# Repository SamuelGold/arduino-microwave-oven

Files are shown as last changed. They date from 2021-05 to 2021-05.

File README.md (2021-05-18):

# A second life for an old microwave oven

<p align="center">
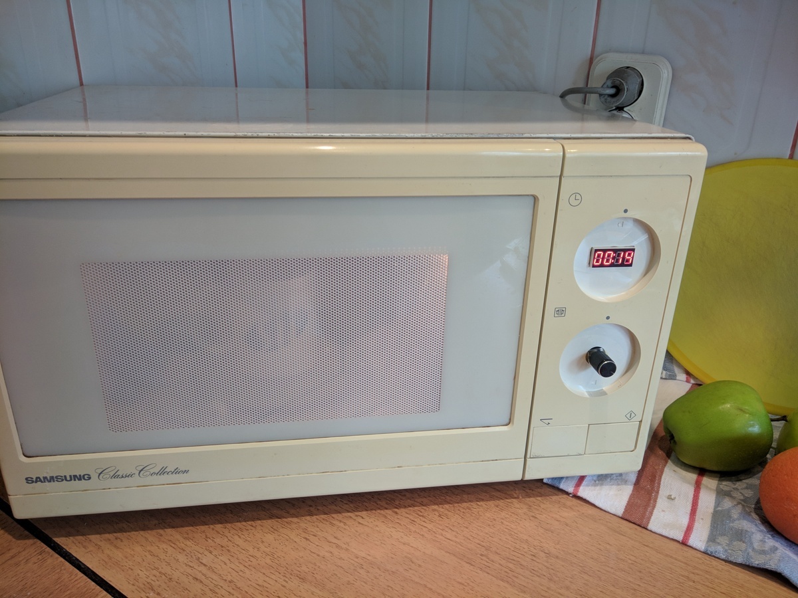
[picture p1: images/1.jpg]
  
</p>

I have a 28 years old oven, Samsung M7136. It so old, than this photo is probably only one of this model on the Internet :)

<p align="center">
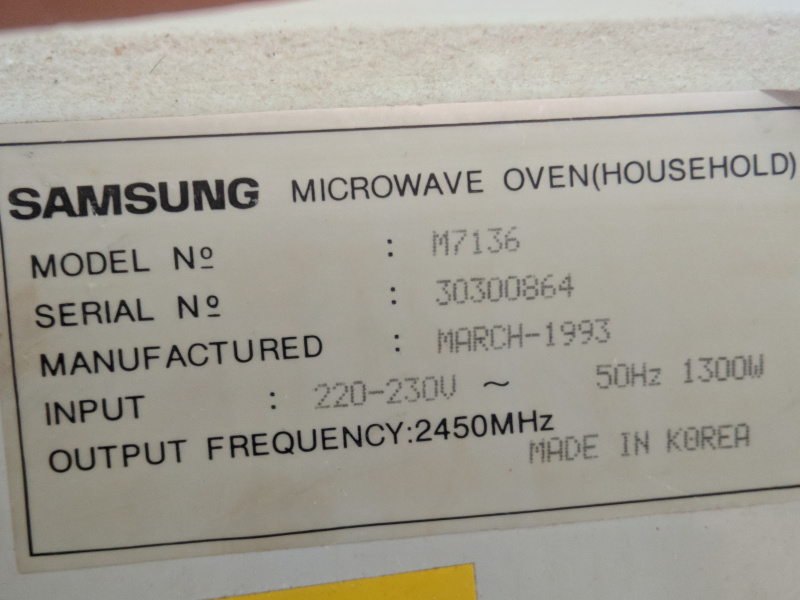
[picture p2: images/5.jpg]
  
</p>

The microwave had been working great, but but one day it stopped. One gear became broken:

<p align="center">
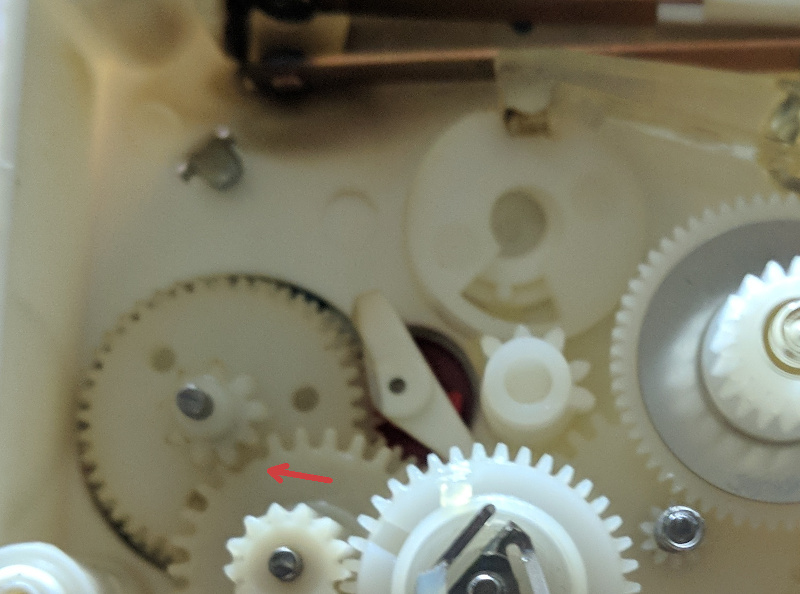
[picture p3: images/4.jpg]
broken mechanism
  
</p>

It was a pity to loose such a great oven an I did not want to multiply waste as well, so I decided to replace its mecanical timer with an electronic one.
If you decide to repeat this experience, please do not remove any switches around the door or termal protections from your oven :)

## Components:

1. Arduino NANO;
2. 2 pcs. 5V 10A x 250V relays, but it is recommended to use 30A relay for the microwave switch instead of 10A one;
3. KY-040 encoder module;
4. TM1637 display module;
5. 5V active buzzer;
6. 5V power supply.

## Connection schematic:

<p align="center">
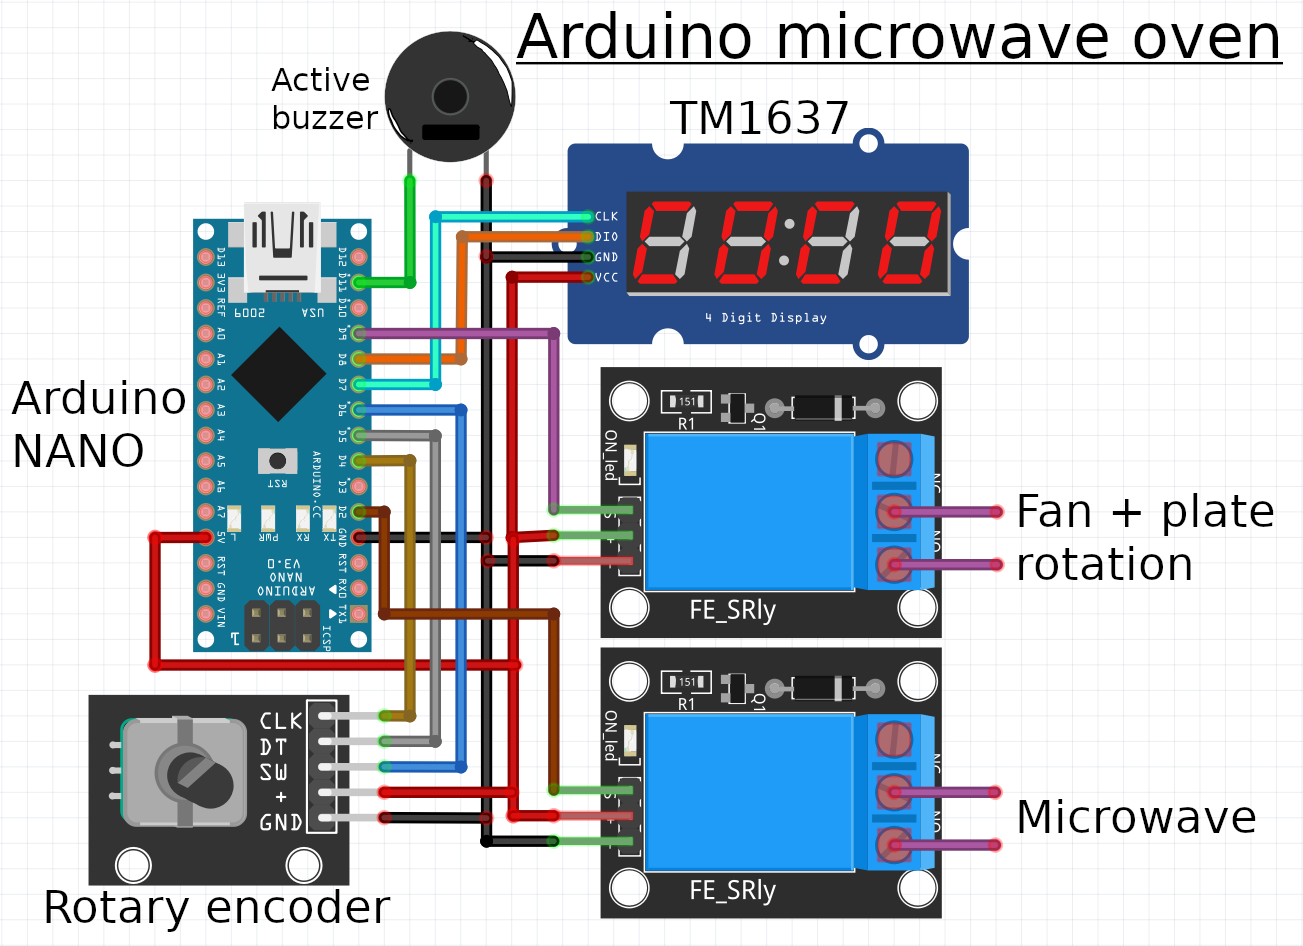
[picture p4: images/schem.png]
  
</p>

## Functionality:
Turn the encoder knob clockwise to start timer and heating process, turn the knob counterclockwise to decrease time and turn it off. Short press on the knob in the turned off state to show the current power level. Long press on the knob in turned off state to change the power level.

Arduino project code is included in this repo.
<p align="center">
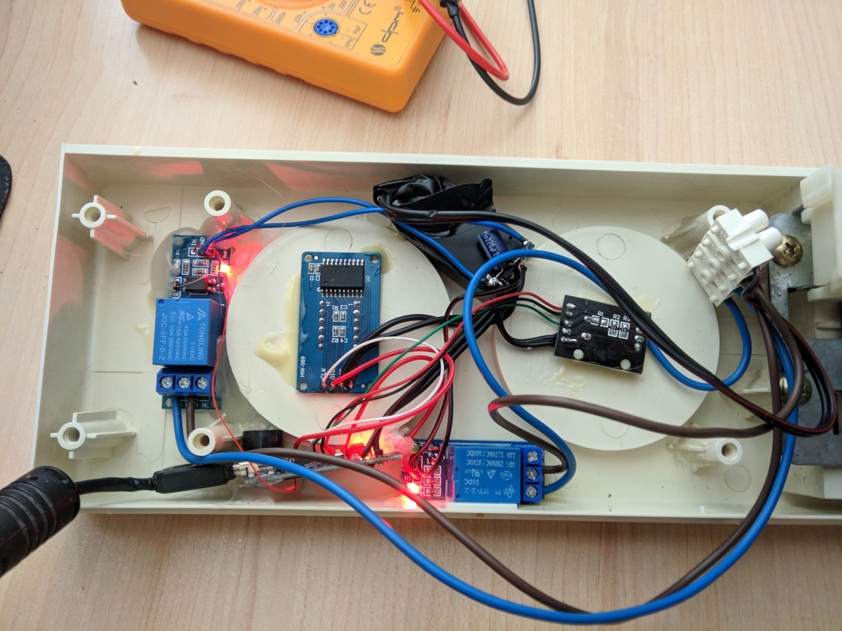
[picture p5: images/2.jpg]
  
</p>

<p align="center">
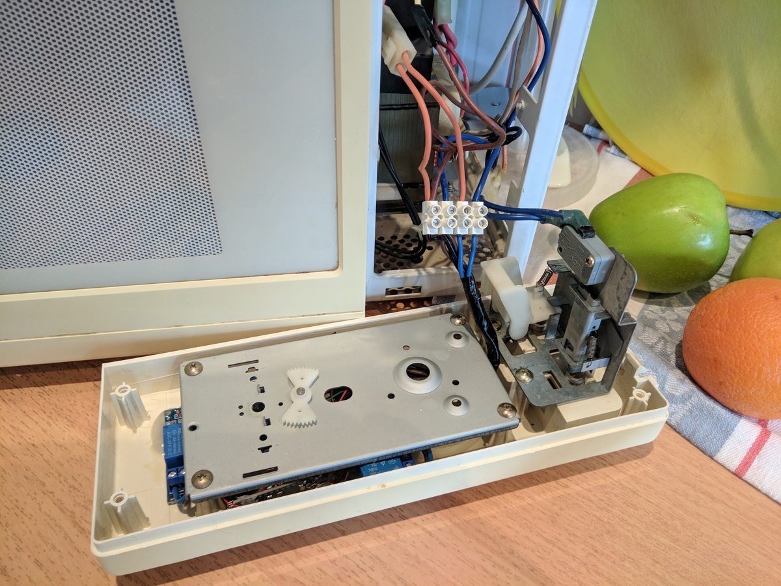
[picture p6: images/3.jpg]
  
</p>

 Remember about safety and have a fun :)

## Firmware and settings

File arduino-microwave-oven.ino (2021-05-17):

#include <TM1637.h>   //Grove segment display library
#include <Encoder.h>  //Paul Stoffregen's encoder library
#include <TimerOne.h>
#include <EEPROM.h>

#define BUZZER_pin         11 /* Active buzzer pin. */
#define DISPLAY_DATA_pin    8 /* TM1637 display data pin. */
#define DISPLAY_CLK_pin     7 /* TM1637 display clock pin. */
#define ENCODER_SW_pin      6 /* Rotary encoder button pin. */
#define ENCODER_DT_pin      5 /* Rotary encoder DT pin. */
#define ENCODER_CLK_pin     4 /* Rotary encoder CLK pin. */
#define MICROWAVE_RELAY_pin 2 /* Relay pin, that turns microwave power on. */
#define MOTOR_FAN_RELAY_pin 9 /* Relay pin, that turns cooler fan and food rotation motor on. */

#define POWER_max        5 /* Power levels number. */
#define POWER_CNTR_mul   4 /* Seconds per one power level. POWER_max * POWER_CNTR_mul = total power cycle time. */
#define SECONDS_max      1200 /* Maximal working time. */
#define SECONDS_CNTR_mul 3 /* Seconds per encoder rotation tik sensivity. */
#define SECONDS_CNTR_max SECONDS_max * SECONDS_CNTR_mul
#define TIME_CNTR_SPEEDUP 30 /* Timer value, after that we should increase the time faster by encoder rotation. */
#define FAN_AFTER_OFF_TIME 5 /* Time to keep fan on after microwaving finished. */

TM1637 disp(DISPLAY_CLK_pin,DISPLAY_DATA_pin);
Encoder knob(ENCODER_DT_pin, ENCODER_CLK_pin);

static int time_counter = 0;
static uint32_t power = 1;
static uint32_t power_counter = 0;
static uint32_t relay_state = 0;
static uint32_t motor_fan_state = 0;
static uint32_t motor_fan_counter = 0;
static long oldPosition = 0;
unsigned long oldMills;
static int finish = 0;
static int updateDisplay = 0;
static int updatePower = 0;
static int displayPower = 0;
static int silent_off = 0;
static int reduse_noise = 0;

static int melody_durations[] = {
6, 8, 8, 8, 16, 10, 10
};

static int pause_durations[] = {
16, 4, 4, 8, 18, 6, 6
};

/* Melody play at the end, used an active buzzer that sounds on power on by itself. */
void beep(){
  
  for (int i = 0; i < sizeof(melody_durations)/sizeof(melody_durations[0]); i++)
  {
    digitalWrite(BUZZER_pin, HIGH);
    delay((melody_durations[i]/2) * 30);
    digitalWrite(BUZZER_pin, LOW);
    delay((pause_durations[i]/2) * 20);
  }
}

/* Turn the microwave on/off */
void set_microwave_relay(uint8_t state){
  /* Turn the fan and the plate rotation on before turn microwave on. */
  if (state)
  {
    set_motor_fan(1);
  }
  
  relay_state = state?1:0;
  digitalWrite(MICROWAVE_RELAY_pin, state?0:1);
}

/* Turn the fan and the plate rotation on/off. */
void set_motor_fan(uint8_t state){
  /* Enable noise reducing. */
  if (!state)
  {
    reduse_noise = 2;
  }

  motor_fan_state = state?1:0;
  digitalWrite(MOTOR_FAN_RELAY_pin, state?0:1);
  motor_fan_counter = 0;
}

/* 1/second interrupt callback. */
void timerCallback()
{
  /* IDLE state. */
  if (!time_counter && !relay_state && !finish)
  {
    /* Keep fan and rotation motors several more seconds on after microwave off. */
    if (motor_fan_state)
    {
      motor_fan_counter++;
  
      if (motor_fan_counter > FAN_AFTER_OFF_TIME)
      {
        set_motor_fan(0);
      }
    }

    /* Encoder press process, show power level. On long press- increase the level. */
    if (!digitalRead(ENCODER_SW_pin))
    {
      if (!displayPower)
      {
        displayPower = 1;
      } else
      {
        updatePower = 1;
      }
    }
  }

  /* Working state, process time counting and the power regulation. */
  if (!finish && (time_counter || relay_state))
  {
    time_counter -= SECONDS_CNTR_mul;

    /* Time ended. */
    if (time_counter <= 0)
    {
      time_counter = 0;
      finish = 1;
      power_counter = 0;
      set_microwave_relay(0);
    } else
    {
      /* Regulate power depending on power level settings. */
      if (power_counter < (power * POWER_CNTR_mul))
      {
        set_microwave_relay(1);
      } else
      {
        set_microwave_relay(0);
      }
      
      power_counter++;

      /* Loop the power counter. */
      if (power_counter >= (POWER_max * POWER_CNTR_mul))
      {
        power_counter = 0;
      }
    }
    updateDisplay = 1;
  }

  /* Reduse noise influence on encoder. */
  if (reduse_noise)
  {
    reduse_noise--;
  }
}

void setup() {
  pinMode(MICROWAVE_RELAY_pin, OUTPUT);
  pinMode(MOTOR_FAN_RELAY_pin, OUTPUT);
  pinMode(BUZZER_pin, OUTPUT);
  
  pinMode(DISPLAY_DATA_pin, OUTPUT);
  pinMode(DISPLAY_CLK_pin, OUTPUT);
  
  pinMode(ENCODER_SW_pin, INPUT_PULLUP);
  pinMode(ENCODER_DT_pin, INPUT);
  pinMode(ENCODER_CLK_pin, INPUT);

  set_microwave_relay(0);
  set_motor_fan(0);

  /* Restore power settings from EEPROM. */
  power = constrain(EEPROM.read(0),1,POWER_max);

  disp.init();
  disp.set(0);
  
  disp.point(1);
  disp.clearDisplay();

  /* 1/s time init. */
  Timer1.initialize(1000000);
  Timer1.attachInterrupt(timerCallback);

  /* First position of rotary encoder. */
  oldPosition = knob.read();
}

/* Display the timer value. */
void display_seconds(uint32_t seconds) {
  int minutes;

  seconds = (seconds / SECONDS_CNTR_mul);

  if (!seconds)
  {
    disp.point(1);
    disp.clearDisplay();
  } else
  {
    minutes = seconds / 60;
    seconds = seconds % 60;
  
    disp.point(1);
    disp.display(3, seconds % 10);
    disp.display(2, seconds / 10 % 10);
    disp.display(1, minutes % 10);
    disp.display(0, minutes / 10 % 10);
  }
}

void loop() {
  long newPosition;
  unsigned long curMills;

  if (!reduse_noise)
  {
    newPosition = knob.read();
  } else /* Disable encoder for a second */
  {
    newPosition = oldPosition;
    knob.write(oldPosition);
  }

  /* Encoder rotated right. */
  if (newPosition < oldPosition)
  {
    time_counter += oldPosition - newPosition;

    /* Give some more time at the beginning of rotation. */
    if (time_counter < SECONDS_CNTR_mul)
    {
      time_counter = SECONDS_CNTR_mul * 5;
    }

    /* Adjust rotation sensivity. */
    if ((time_counter / SECONDS_CNTR_mul) > TIME_CNTR_SPEEDUP)
    {
      time_counter += oldPosition - newPosition;
    }

    /* Avoid overflow. */
    if (time_counter > SECONDS_CNTR_max)
    {
      time_counter = SECONDS_CNTR_max;
    }

    updateDisplay = 1;
    oldPosition = newPosition;
  }

  /* Encoder rotated left. */
  if (newPosition > oldPosition)
  {
    time_counter -= newPosition - oldPosition;

    if ((time_counter / SECONDS_CNTR_mul) > TIME_CNTR_SPEEDUP)
    {
      time_counter -= newPosition - oldPosition;
    }

    /* Avoid overflow. */
    if (time_counter < 0)
    {
      time_counter = 0;
      silent_off = 1; /* On manual off do not play melody. */
    }
    
    updateDisplay = 1;
    oldPosition = newPosition;
  }

  /* Time finished. */
  if (finish)
  {
    Timer1.stop();
    time_counter = 0;
    display_seconds(time_counter);
    if (!silent_off)
    {
      beep();
    }

    finish = 0;
    silent_off = 0;
    Timer1.start();
  }

  /* Update display if needed. */
  if (updateDisplay)
  {
    display_seconds(time_counter);
    updateDisplay = 0;
  }

  /* Display power level on short press and increase it on the long one. */
  if (displayPower || updatePower)
  {
    if (updatePower)
    {
      power++;
      if (power > POWER_max)
      {
        power = 1;
      }
    
      EEPROM.update(0, power);
      updatePower = 0;
    }
    
    disp.clearDisplay();
    disp.display(0, power);
  }

  /* Encoder button was released, hide the power level info. */
  if (displayPower && digitalRead(ENCODER_SW_pin))
  {
    displayPower = 0;
    disp.clearDisplay();
  }
}
